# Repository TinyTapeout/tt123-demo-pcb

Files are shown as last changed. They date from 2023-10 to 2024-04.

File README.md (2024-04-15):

# TinyTapeout Demo Board for chips TT01, TT02 & TT03 



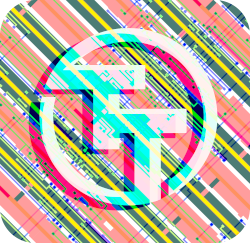
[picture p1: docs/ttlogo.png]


[TinyTapeout](https://tinytapeout.com/) is an educational project that makes it easier and cheaper than ever to get your digital designs manufactured on a real chip!

# PCB

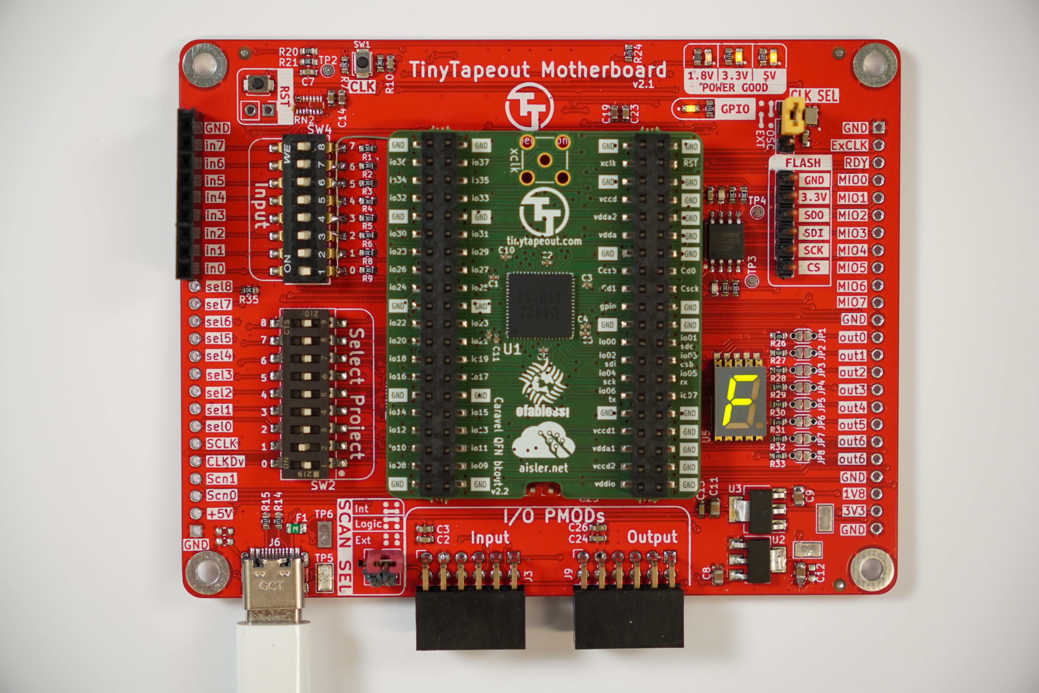
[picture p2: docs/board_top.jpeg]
boards


[More photos](https://photos.google.com/share/AF1QipMfPNW5h1ToMmdxPiXkDxMh_URZRe7d-SqbOogF8Wc6BN0UmT55_Mc50GN2rfgwhA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)

# Pinout and Quickstart

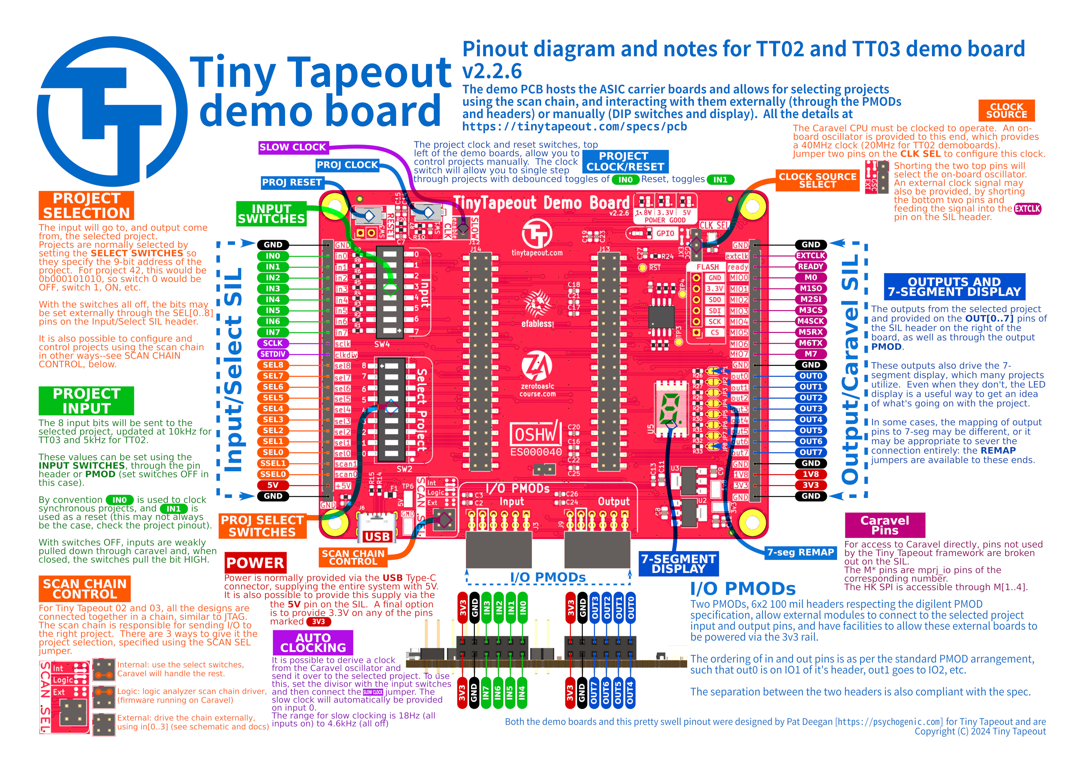
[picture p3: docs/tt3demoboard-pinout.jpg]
pinout


# Setup

Select the design you want to load. See here for all the designs:

* https://tinytapeout.com/runs/tt01/
* https://tinytapeout.com/runs/tt02/
* https://tinytapeout.com/runs/tt03/

Plug in the power via USBC and the design should be active. See the documentation for the design for how to test.
If there are no docs, open an issue on the design's repo!

## Clock divider

To slow down the generated clock:

https://github.com/TinyTapeout/tinytapeout-02/blob/tt02/INFO.md#clock-divider

## Firmware

You shouldn't need to update the firmware in most cases.

If you need firmware for external scan controller you can get the firmware from here:

https://github.com/TinyTapeout/tinytapeout-02/tree/tt02/verilog/dv/scan_controller_ext

Compile and flash using the Makefile.

## We are very happy to be sponsored by

* [Efabless](https://efabless.com/)

## Features

* Lots of testpoints, big ground pads
* Expose useful signals from ASIC:
  * ready - the sync pulse when the chain is updated
  * slow clock
  * the safety scan chain pins (all those starting with ext_scan...)
  * Expose flash programming on a standard cheap footprint for some common USB FTDI programmer
* Lots of explanatory silkscreen
* Board version and link to this repo on the silkscreen
* USB C PSU, 3.3v and 1.8v
* Adjustable clock / single step
* 9 DIP switch for design select (or jumpers)
* 8 DIP switch for inputs - should last for some fiddling but don’t need to be too heavy duty - could be buttons.
* 8 LEDs for outputs: 7 segment display inc dot
* Include PMOD headers for IOs
* Pluggable into breadboard
* Flash for firmware used to setup GPIO
* Work for TT01, TT02 & TT03
* Design for test - single sided probe test points, mounting / alignment holes

## Flashing

[See the firmware repo here](https://github.com/TinyTapeout/tt123-demo-fw)

## CHANGELOG

See [CHANGELOG.md](CHANGELOG.md)

## Resources

* [Technical info on the chip, pinout, scanchain](https://github.com/TinyTapeout/tinytapeout-02/blob/tt02/INFO.md)
* [Breakout PCB](https://github.com/TinyTapeout/breakout-pcb)
* [Datasheet on Caravel: the padring and management core](https://caravel-harness.readthedocs.io/en/latest)
* Logo created at [oshwmark by CapableRobot](http://oshwmark.capablerobot.com/)

## License

* The PCB is licensed under the [Apache2 License](LICENSE)
* The documentation is licensed under the [CC0 License](CC0_license)

## Open Source Hardware

[ES000040](https://certification.oshwa.org/es000040.html)

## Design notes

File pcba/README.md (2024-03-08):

PCB assembly files
Current version 2.2.5 boards.

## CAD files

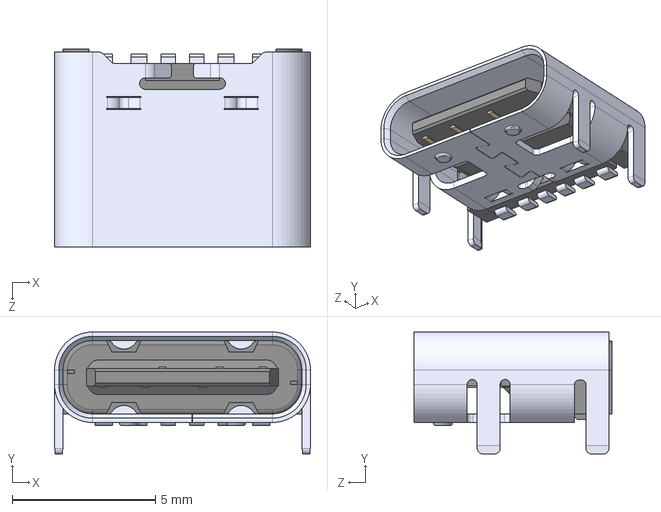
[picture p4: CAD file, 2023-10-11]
3dmodels/UJC-HP-3-SMT-TR.step
8.94 x 4.26 x 6.90 mm

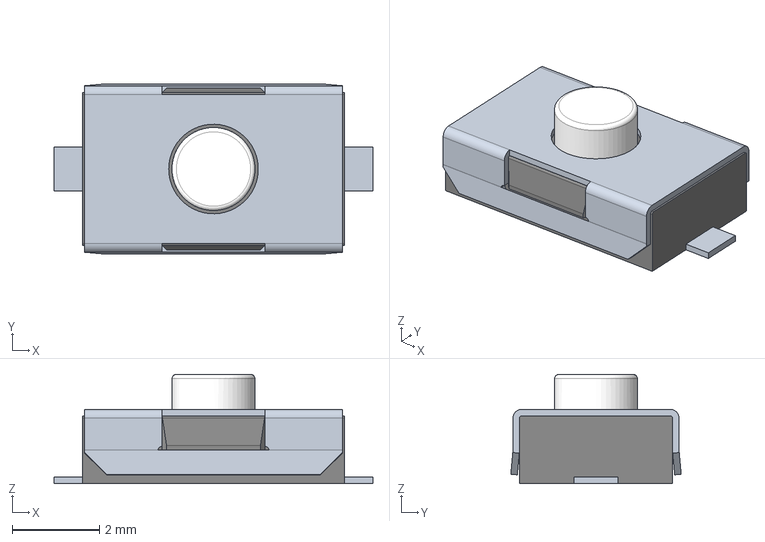
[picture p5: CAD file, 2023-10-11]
3dmodels/434121025816.step
7.30 x 3.90 x 2.50 mm

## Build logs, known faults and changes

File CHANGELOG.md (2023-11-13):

# Changelog

## [2.2.5] - 2023-11-13

7-segment display used required new footprint: created and placed. Tests indicate caravel may be clocked up to about 28MHz, osc changed to 20MHz.  Added a DNP pull-up for nRST, just in case internal isn't around or doing the job.  DNPed PMODs.

## [2.2.4] - 2023-10-27

Fix for bring-up discovery of Caravel reset issue.  The pull-up on the ~RESET pin is insufficient for stable power-up: it rises along with the supply and glitches operation.  Tests show adding a cap to delay transition looks sufficient for decent boot.

Also exposed the slow clock config/enable using jumper (J12)

## [2.2.3] - 2023-10-11

Minor tweaks for pick&place and silkscreen adjustments.

## [2.2.2] - 2023-10-06

Component replacements for PCBA/costing and related layout work.

### Major changes

- Tactile switches swapped out for bigger components
- LDOs swapped out for more efficient components
- USB-C connector changed for unit that only handles power
- layout positioning of 1 symbol -> 2 placements for carrier board

## [2.2.0] - 2023-10-01

Rework and complete re-route for the TT 1-3 mainboard.

### Major changes

- Flipped the input DIP switch so physical and logic match-up (ON is high)
- Fix: reset and clock only affect project, i.e. mapped to in 0 and 1
- Fix: debouce circuits reworked, positive edge on button press
- Mapped Caravel HK SPI to Pico
- Remapped external pin headers
- Removed resistor networks as we can rely on caravel pull-downs
- Routed such that manual remap of output to 7-segment display won't involve avoiding traces while cutting jumpers   

## [2.1.0] - 2023-07-19

Mainboard for TT 01, 02 and 03 released, with DIP switches for inputs and selection, PMOD I/O,
7-segment display and Raspberry Pi Pico footprint.

This is the preliminary release of the schematic, for review and prototyping.

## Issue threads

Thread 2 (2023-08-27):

Make it easier to remove the carrier board

mattvenn, 2023-08-27:
Removing the carrier is very hard. Maybe add pokey hole to push it out from the back?

psychogenic, 2023-08-28:
Hm, could you describe your vision/requirements for this pokey hole?  This is a 2-layer board and the Pico is right under there... so what's a pokey hole that's better than just levering the thing out, but is doable without too much disruption?

mattvenn, 2023-08-29:
updated title and comment.
the issue atm is that you can't flash it with the board in place, so every time I tried new firmware I had to lever it out
I bent the pins after a few levering outs

psychogenic, 2023-10-11:
There's no good way to do this... I think it matters little, now that we can program the flash in place through HK SPI.  Suggest we close.

Closed 2023-10-11.

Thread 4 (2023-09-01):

fix the dip switches so that on is on

mattvenn, 2023-09-01:

psychogenic, 2023-10-11:
Handled in v2.2.x, removed resistor networks as we can count on chip PDs, using pull-up only on inputs, flipped things around for input dip switch.

Closed 2023-10-11.

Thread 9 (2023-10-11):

name change - from mother board to demo board.

mattvenn, 2023-10-11:
change silk text on the front to 'TinyTapeout demo board'
update schematic from 'motherboard' to 'demo board'

psychogenic, 2023-10-11:
Changed for v2.2.3, fab run #2

Closed 2023-10-11.

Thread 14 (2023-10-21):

do we need an 'enable clock divider' toggle

mattvenn, 2023-10-21:
at the moment, you have to put a jumper between clkdv and 3.3v to enable it

mattvenn, 2023-10-22:
and would be good to visibly see it easily

mattvenn, 2023-10-23:
can see it with a firmware change to show it on the management gpio

psychogenic, 2023-10-24:
You're thinking just a 2-pin jumper to high for this?  And visibility: can we pwm the gpio pin at the rate of that clock, or something like that?

mattvenn, 2023-10-24:
yes exactly, just a 2 pin jumper. ATM I have to have a wire handy to connect the clkdiv pin to 3.3v. Something like what we have for the scan chain drive select.

I've already got a firmware that shows the frequency on the gpio led. So that's already working.

psychogenic, 2023-10-27:
Have this as a jumper, next to manual clock MOM.
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

Closed 2023-11-09.

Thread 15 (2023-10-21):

change oscillator to 20M?

mattvenn, 2023-10-21:
needs testing first

psychogenic, 2023-10-24:
We can test by feeding in 20M and changing the clock select jump.  But did we need something with a funny duty cycle for this to work?  If so, would that be true for TT3 as well?

mattvenn, 2023-10-24:
Yes, we did test this a bit in the bringup. TT3 has a different chain that should mean we can just use an oscillator.
I'll check how fast we can go with a 50% duty cycle and then make a call on the oscillator for TT2

mattvenn, 2023-11-09:
tested up to 28M, so let's go with a 20M oscillator

https://discord.com/channels/1009193568256135208/1162346245088608366/1166759290665705485

psychogenic, 2023-11-13:
Ok, done, changed for a 20M WE osc with same footprint.

psychogenic, 2023-11-13:
Changed to 830208220401, another Wurth IQXO-791 series osc.  It's the hi-fi version with the same footprint (only the best for my TT friends) but the 831056293 could probably do the trick as well, for a few pennies less.

Closed 2023-11-13.

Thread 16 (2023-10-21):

Something wrong with power up initialisation

mattvenn, 2023-10-21:
the board takes some amount of time before it starts working.

## tests

Power on and wait for chain to start

board d part 2

-  2:15
-  1:30
-  2:40
-  1:48
-  1:03

Board c part 1

-  2:30
-  0:40
-  1:15

## reset test

Hold in reset for 3 mins
Release and wait for chain to start

- 0:00
- 0:00
- 0:00
- 0:00

Selected design's led segments are immediately visible when powered up while reset asserted

## other observations

Another clue: once it's working it stays working. Can change to ext or la mode and scan chain always comes back
I can also power off, ground both select pins, wait 5 seconds, power on and it still continues to work

to go back to 'non working state' needs a few minutes.

## thoughts

unitialised state? but there isn't any reg larger than 9 bits in the scan controller https://github.com/TinyTapeout/tinytapeout-02/blob/tt02/verilog/rtl/scan_controller/scan_controller.v

Is reset ok? even with chip held in reset with a wire doesn't help

Pull-ups/ downs by caravel won't work until after reset.
So either need to be added to the board or might be resolved by some firmware?

even with the select pins both pulled high directly with wires when board starts, still there is this variable delay

mattvenn, 2023-10-22:
Takes 260 led flashes for board 2 to start

mattvenn, 2023-10-23:
missing pulldowns on design select and wrong setting in the firmware led to the scan chain state machine getting confused
fixed with firmware

Closed 2023-10-23.

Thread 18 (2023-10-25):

feedback on v2.2.3

mattvenn, 2023-10-25:
* DNP memory programming header
* DNP PMOD header
* 7 seg not soldered properly on 2 of 4 boards
* board doesn't reset properly
* reset is floating
* reset should be renamed to n_reset

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

floating reset (is pulled up by internal caravel)
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

works with a 1uf cap soldered between reset and gnd:
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

psychogenic, 2023-10-27:
Have set the DNPs at Aisler.  Have the reset RC cap solution in latest rev, as well as the ~rst naming on the symbol.

psychogenic, 2023-11-13:
Headers J1, J3 and J9 are DNPed and excluded @ aisler.  WE 7-seg footprint was different enough to warrant a new one, which I created and populated. nRST cap fix applied, and added a DNP pull-up in case we find the internal isn't around or doing the job.  Submitted as revision 11 @ aisler, closing issue.

Closed 2023-11-13.

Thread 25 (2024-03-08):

feedback on the pinout doc

mattvenn, 2024-03-08:
contrast of the 7-seg could be improved.

7 seg looks a bit weird
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

Follow branding guidance (TinyTapeout -> Tiny Tapeout) (saw a ref to tinytapeout in scanchain control)

Would re-write this:
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

to:

The clock and reset buttons are debounced switches connected to inputs 0 and 1 respectively. Not all projects use this convention, but for those that do, these are convenient ways to manually single step and reset.

would rewrite the 40M clock part of this:
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

to:

which provides a 40MHz clock (20MHz for TT02 demoboards)

Rewrite this:
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

To use this, set the divisor with the input switches and then connect the slow clk jumper. The slow clock will automatically be provided on input 0.

Hard to fit in, but a few examples of slow clock settings would be nice, like the min and max :
all off = 2.3kHz
all on = 9Hz

Rewrite 'as fast as scanchain can manage' here:
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

To: 10kHz for TT03 and 5kHz for TT02.

run a spellcheck on the text. I saw a few: seperation -> separation. there might be more.

mattvenn, 2024-03-08:
Also please add the pinout diagram into this repo

psychogenic, 2024-03-08:
All changes made, hacked up 7-seg image, pinout uploaded and in readme.

psychogenic, 2024-03-08:
Done

Closed 2024-03-08.

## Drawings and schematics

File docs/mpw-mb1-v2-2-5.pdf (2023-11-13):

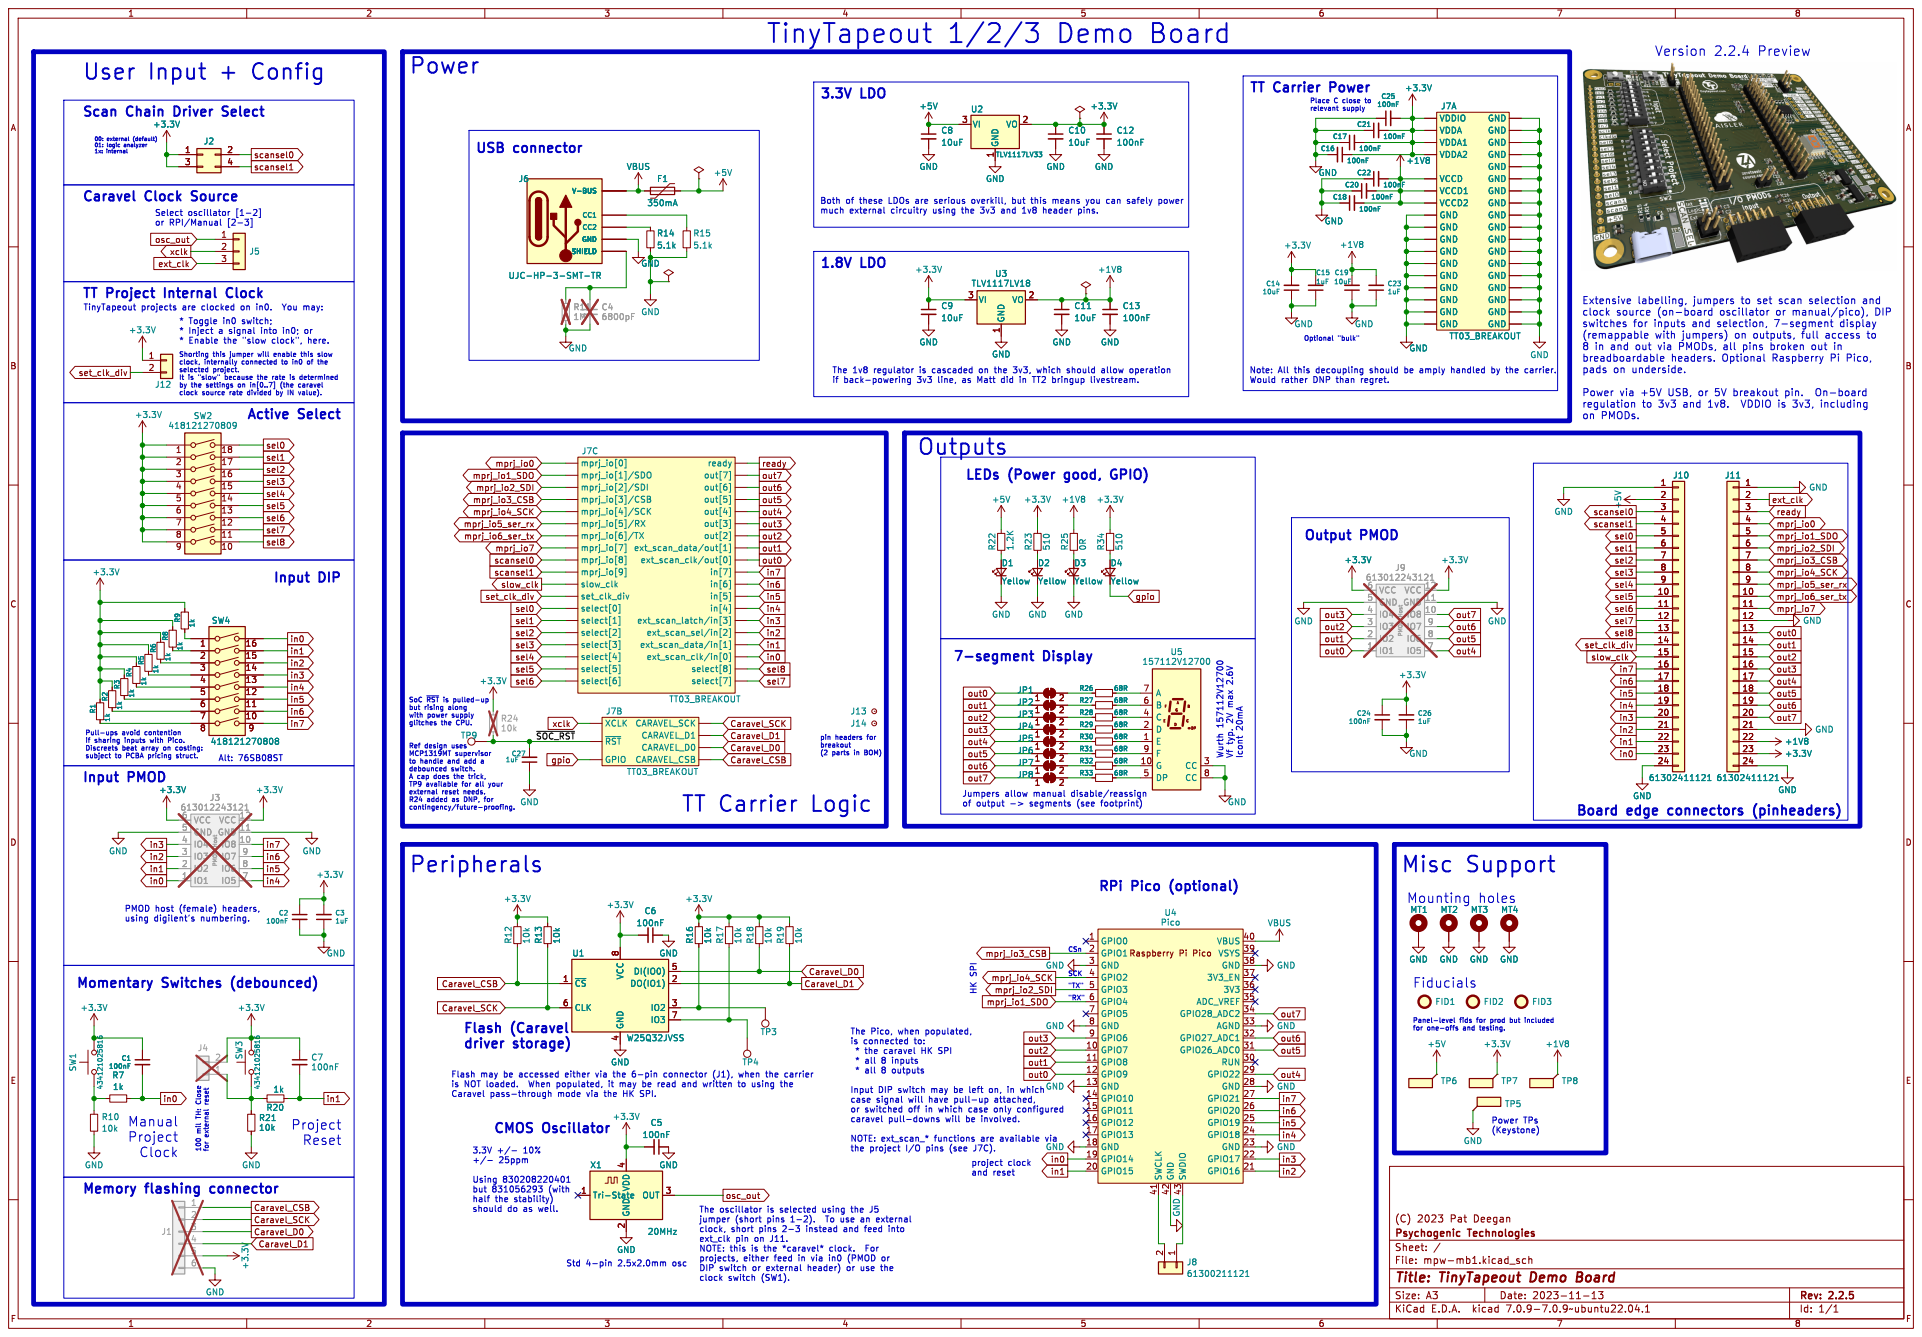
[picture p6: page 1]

Scan Chain Driver Select

1 VO 2 VI 3 U3 TLV1117LV18 +3.3V GND GND

J6 UJC-HP-3-SMT-TR

GND GND GND GND GND

8 in and out via PMODs, all pins broken out in

LEDs (Power good, GPIO)

SoC ~{RST}is pulled-up

to handle and add a

project clock and reset TT Carrier Logic

half the stability) should do as well. Flash (Caravel
driver storage)

The Pico, when populated,

Input DIP switch may be left on, in which

Id: 1/1 Title: TinyTapeout Demo Board

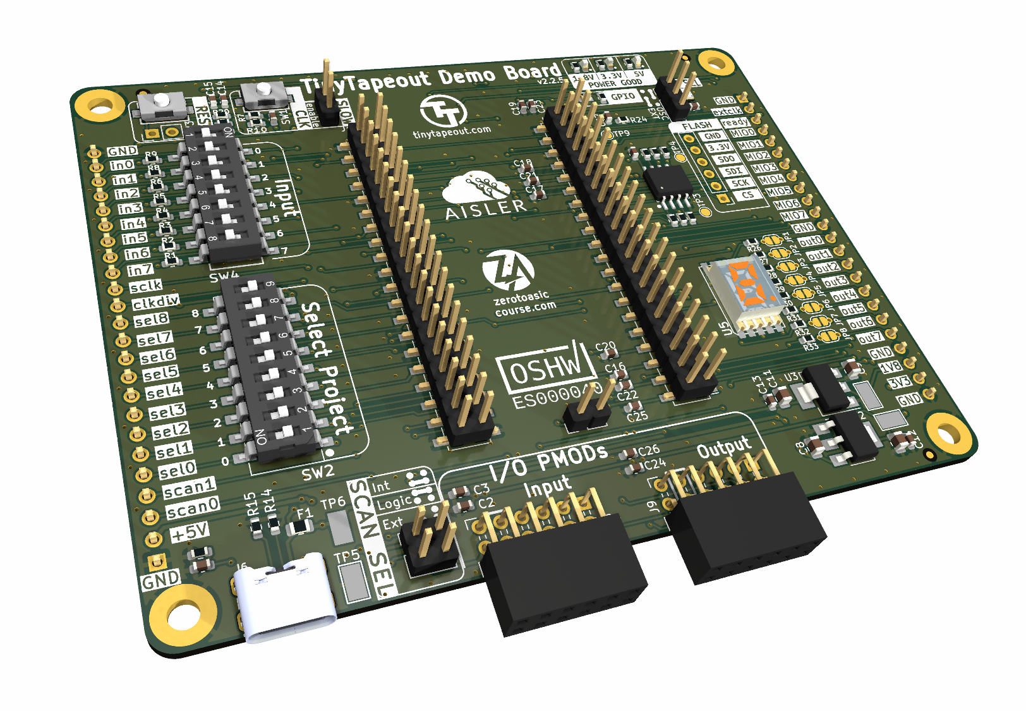
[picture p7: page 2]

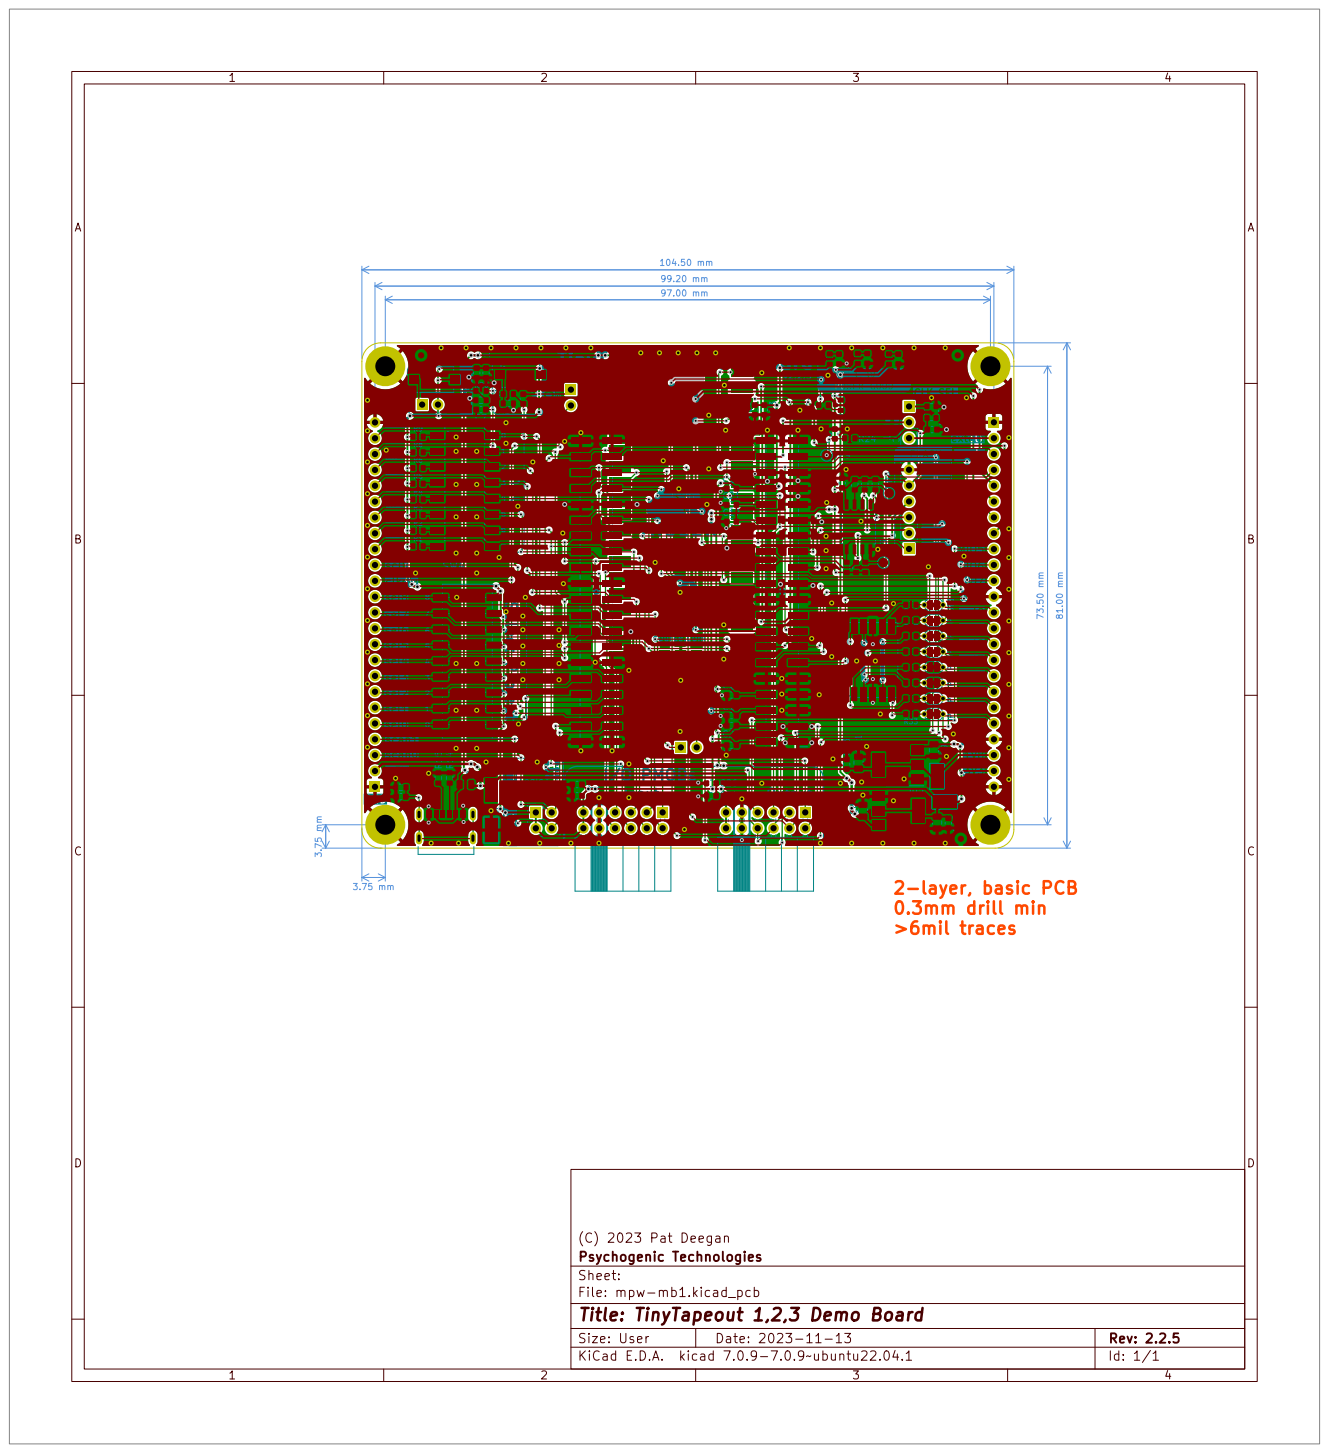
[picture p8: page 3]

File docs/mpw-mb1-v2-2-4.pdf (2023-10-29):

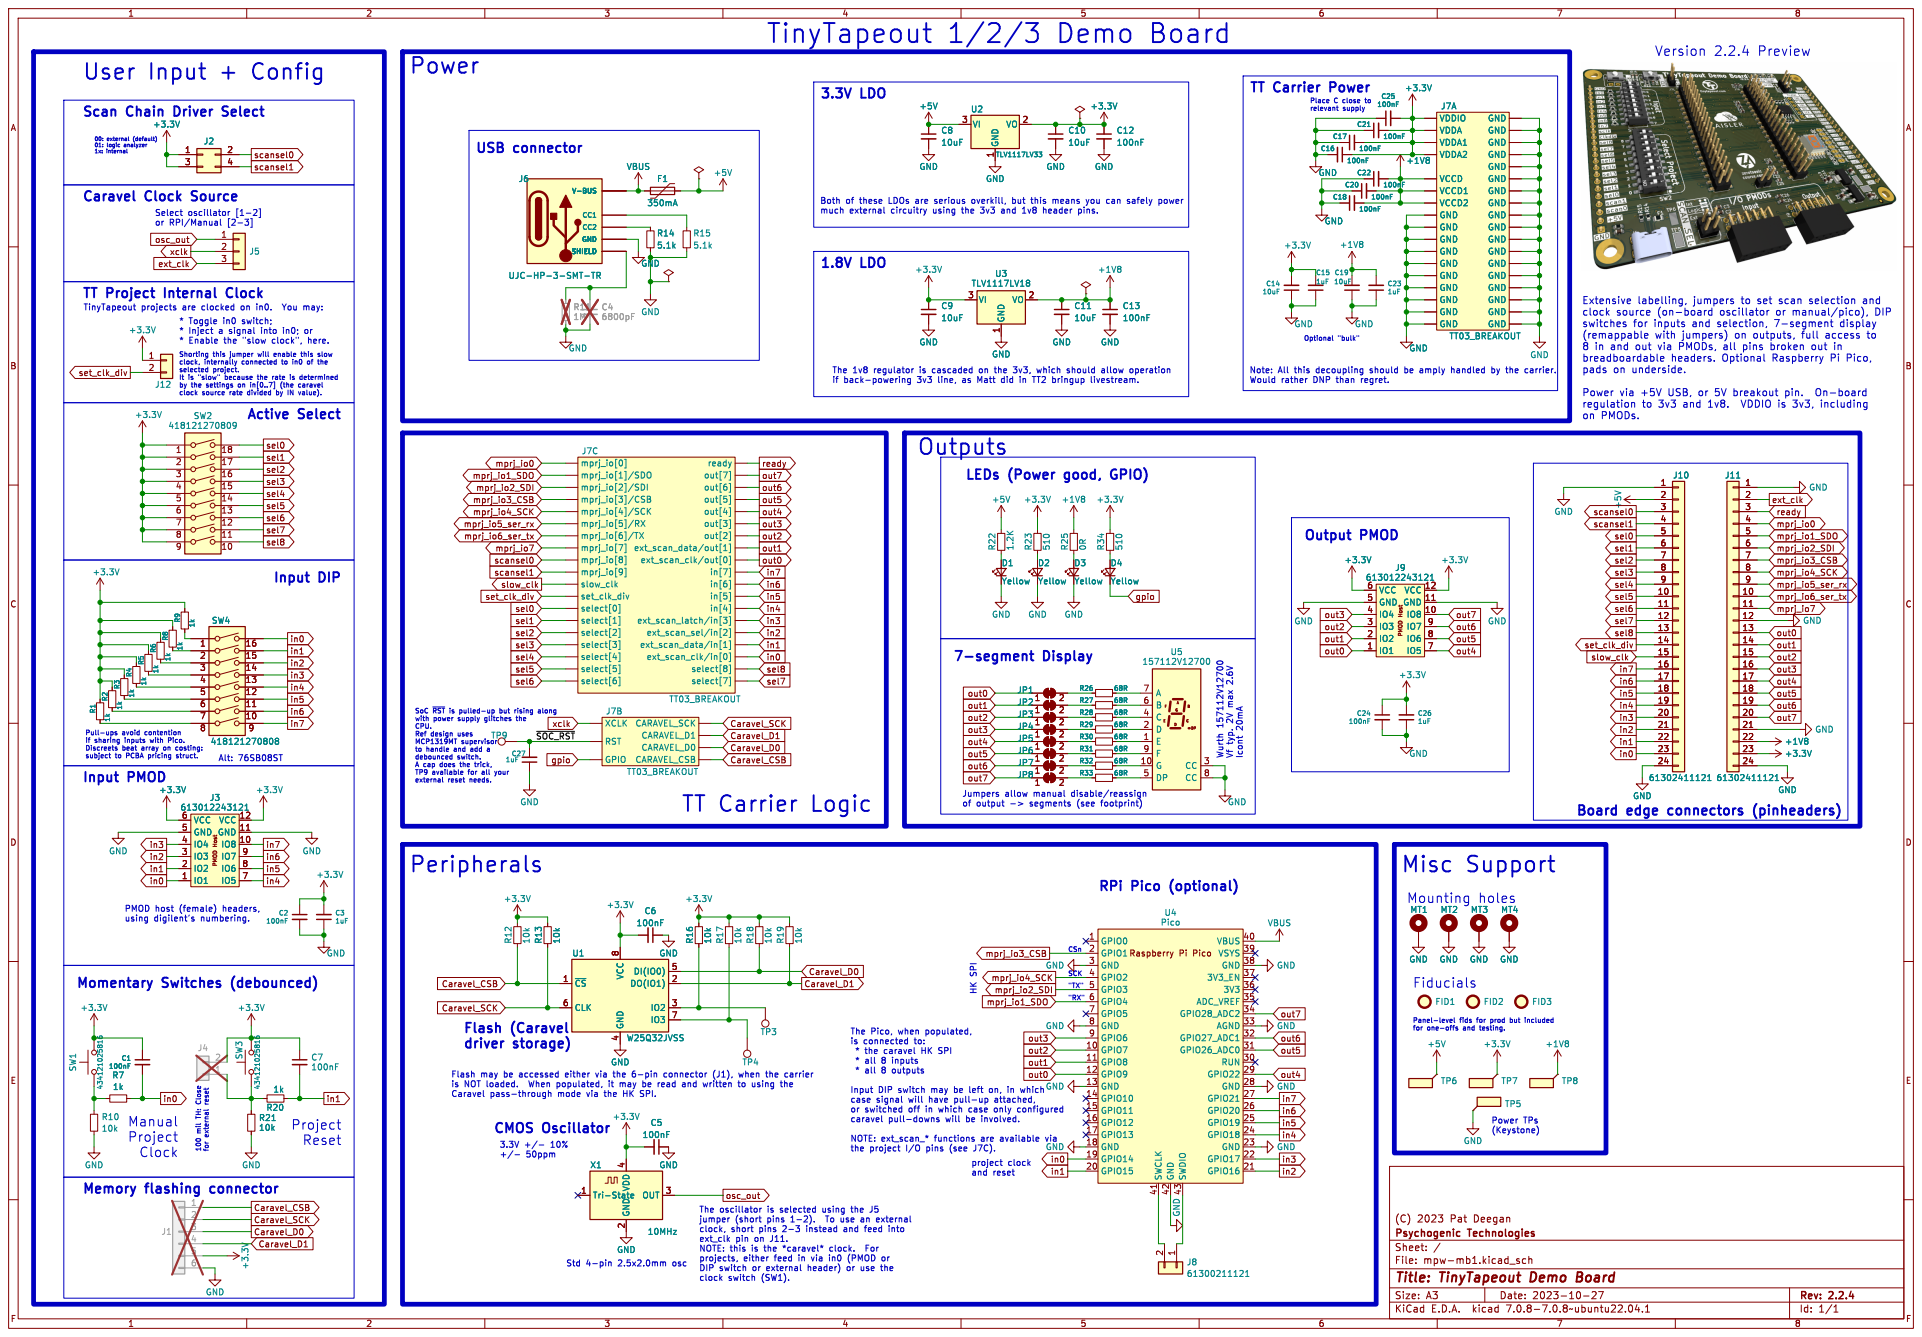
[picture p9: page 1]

J6 UJC-HP-3-SMT-TRGND
CC1 V-BUS CC2 SHIELD

J6 UJC-HP-3-SMT-TR

TT Project Internal Clock

8 in and out via PMODs, all pins broken out in

LEDs (Power good, GPIO)

to handle and add a

Board edge connectors (pinheaders)

Input DIP switch may be left on, in which

the project I/O pins (see J7C).

Id: 1/1 Title: TinyTapeout Demo Board

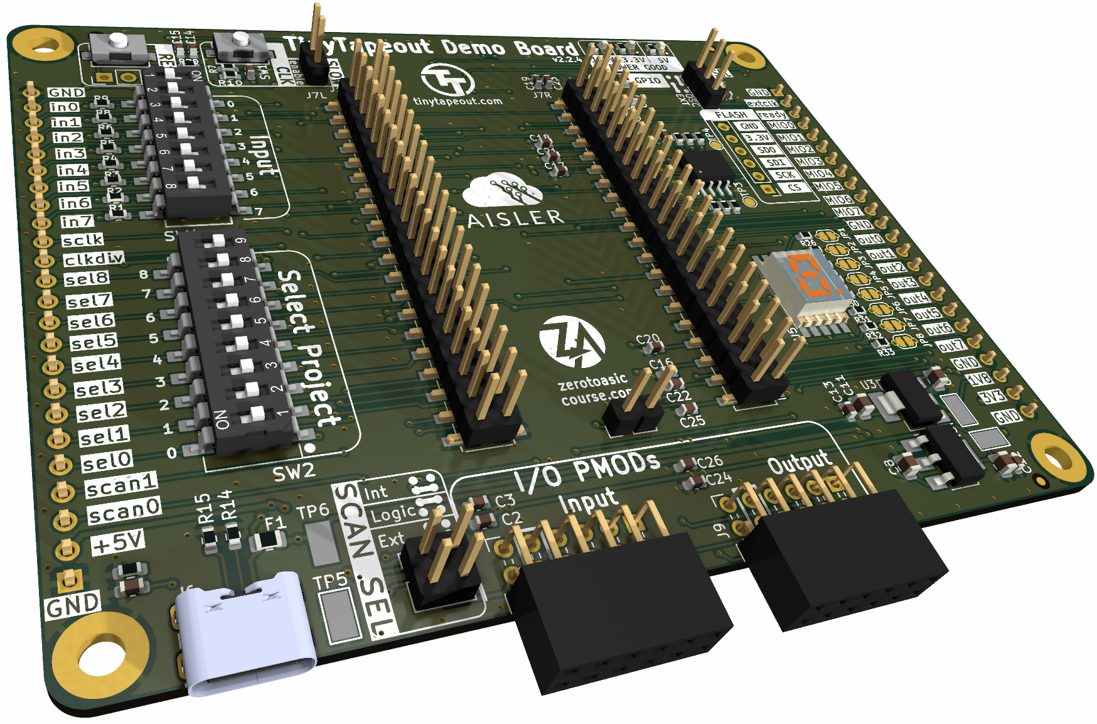
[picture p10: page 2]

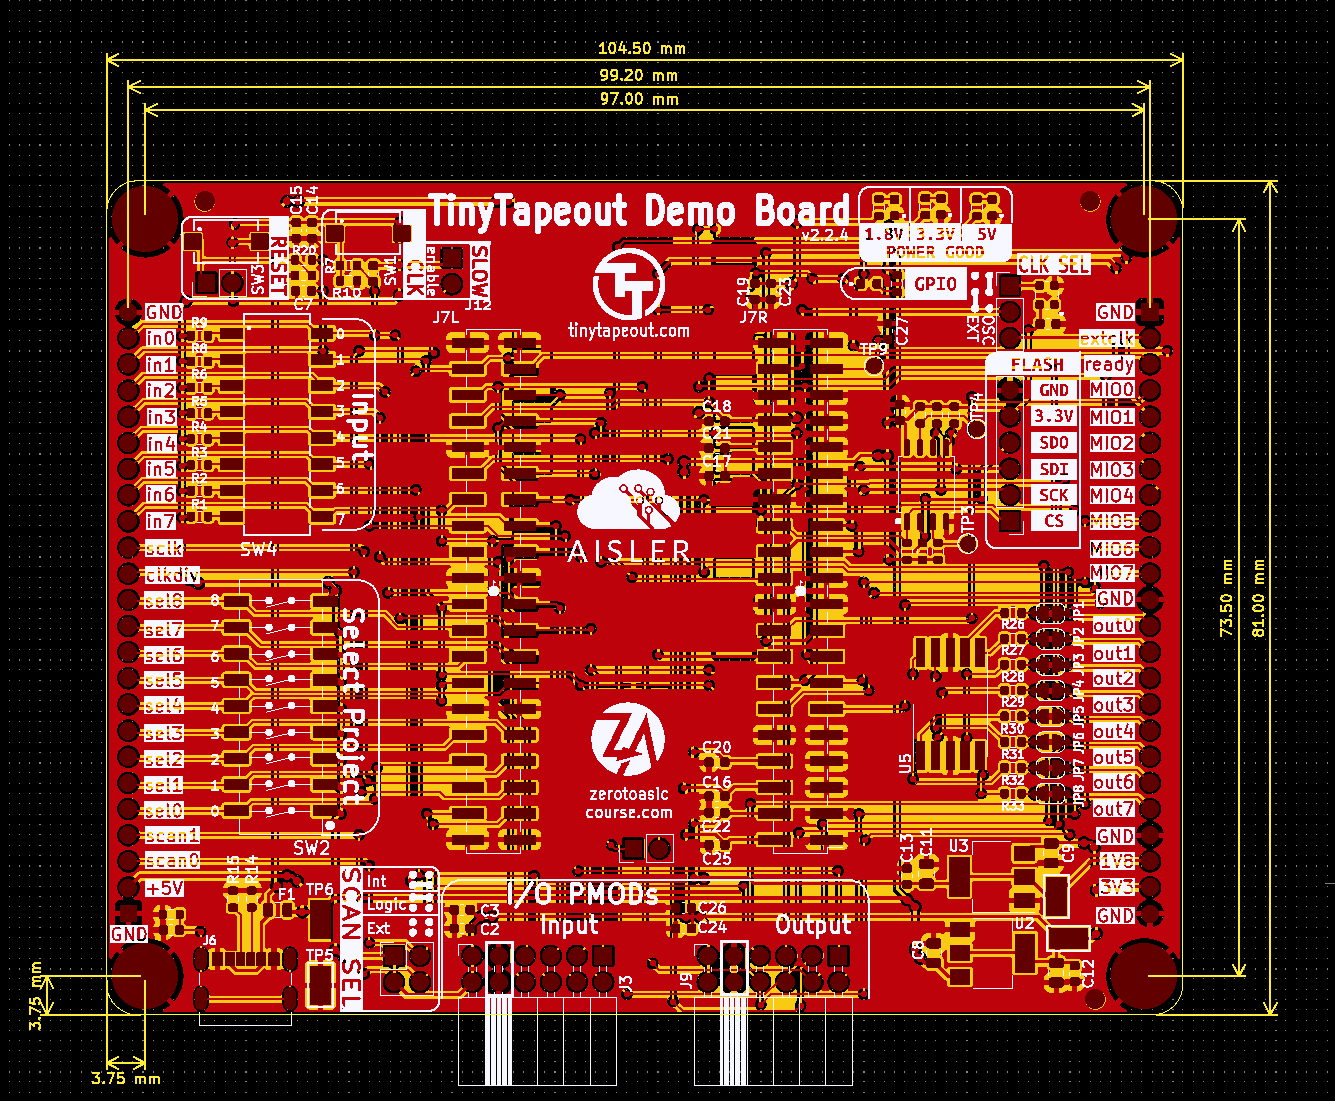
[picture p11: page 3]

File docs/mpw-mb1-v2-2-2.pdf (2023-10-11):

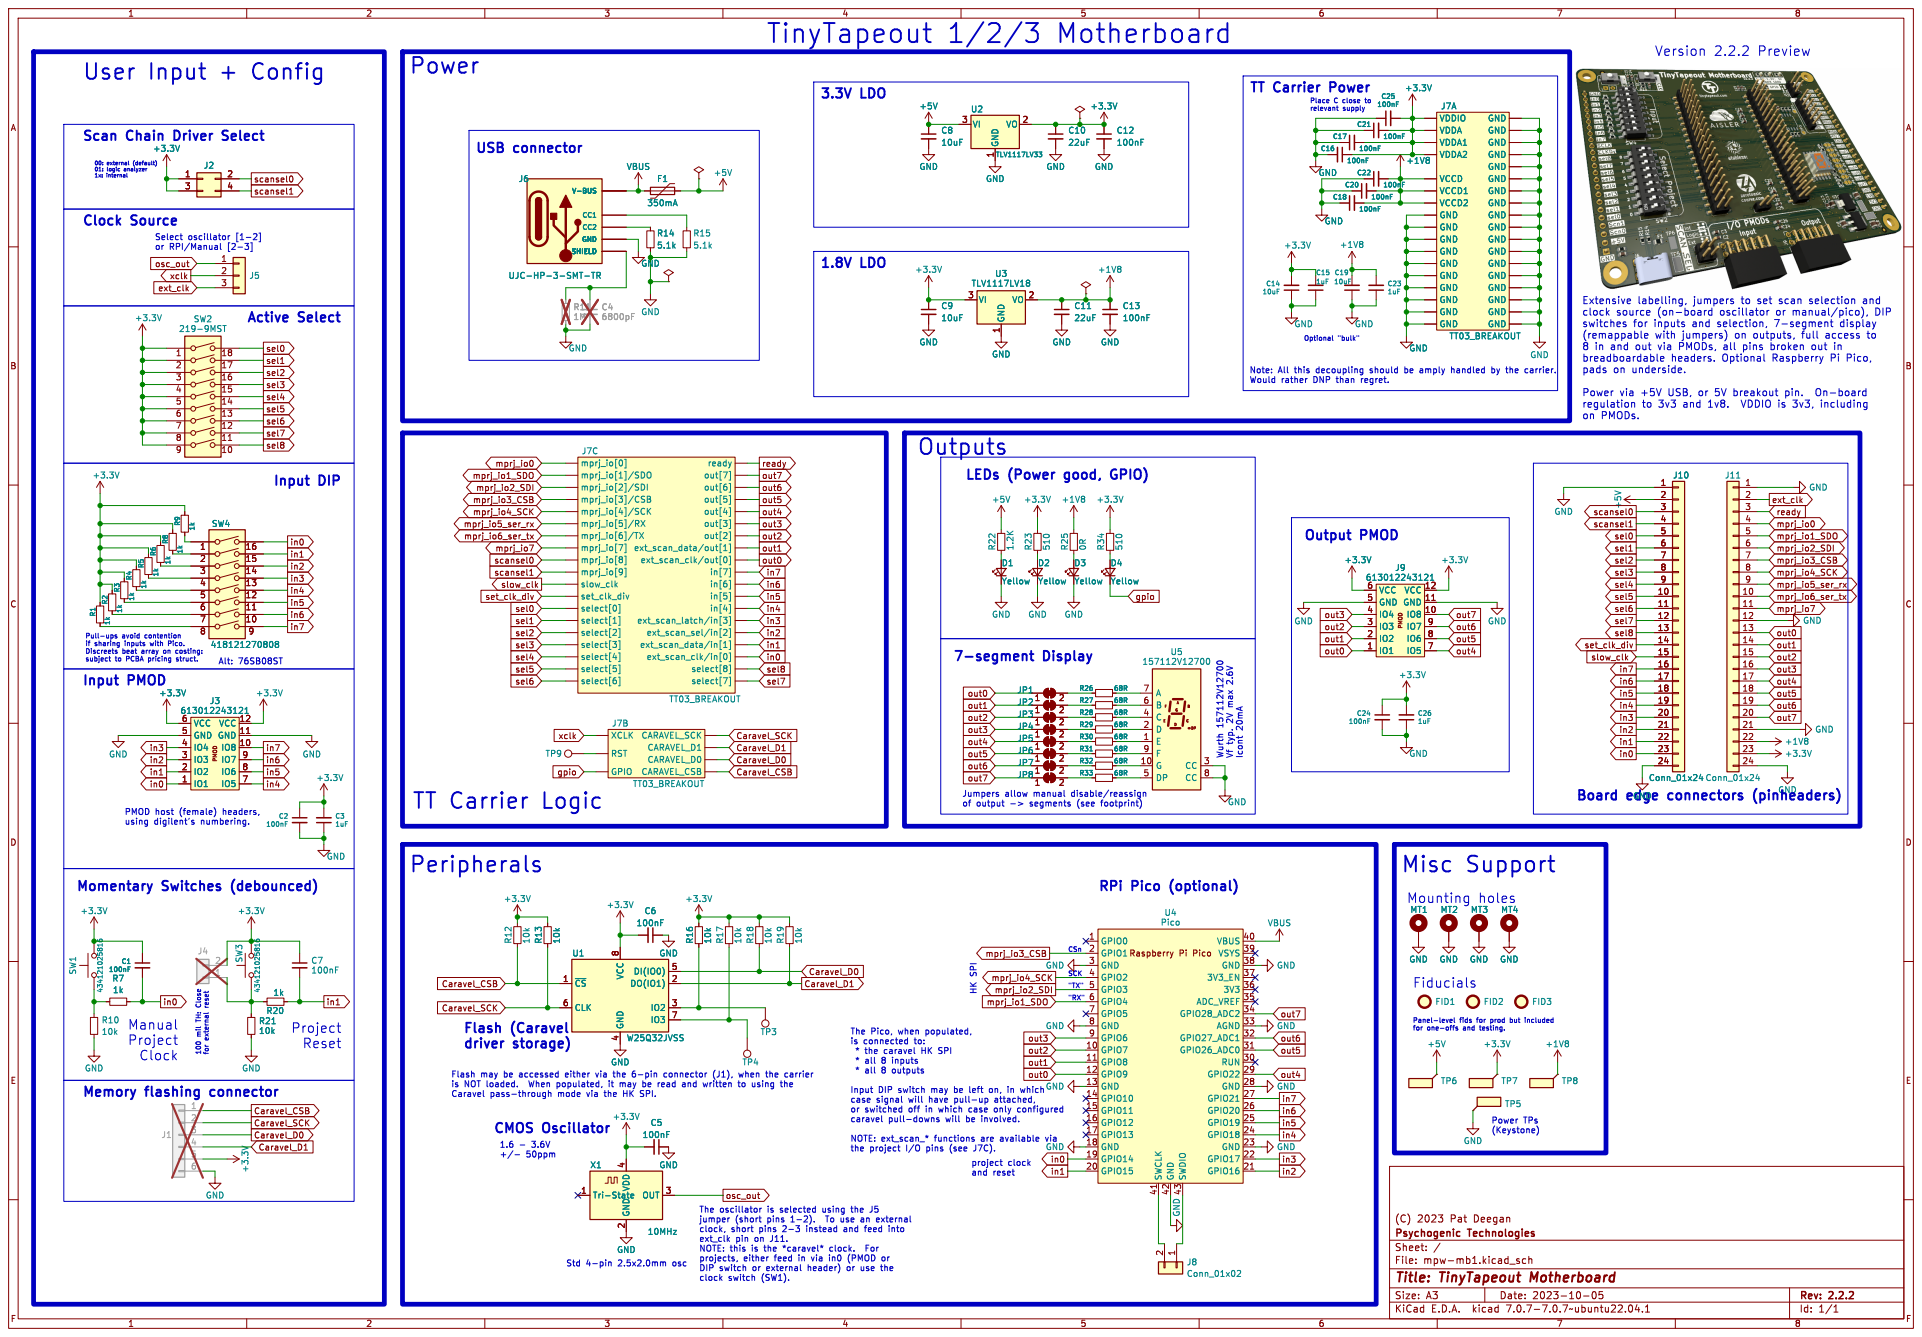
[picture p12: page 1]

SCK User Input + Config

1 VO 2 VI 3 U3 TLV1117LV18 GND GND GND GND

GND GND GND GND GND

J6 UJC-HP-3-SMT-TR

8 in and out via PMODs, all pins broken out in

out7
Jumpers allow manual disable/reassign

CSn Momentary Switches (debounced)

Input DIP switch may be left on, in which

project clock and reset

Id: 1/1 Title: TinyTapeout Motherboard

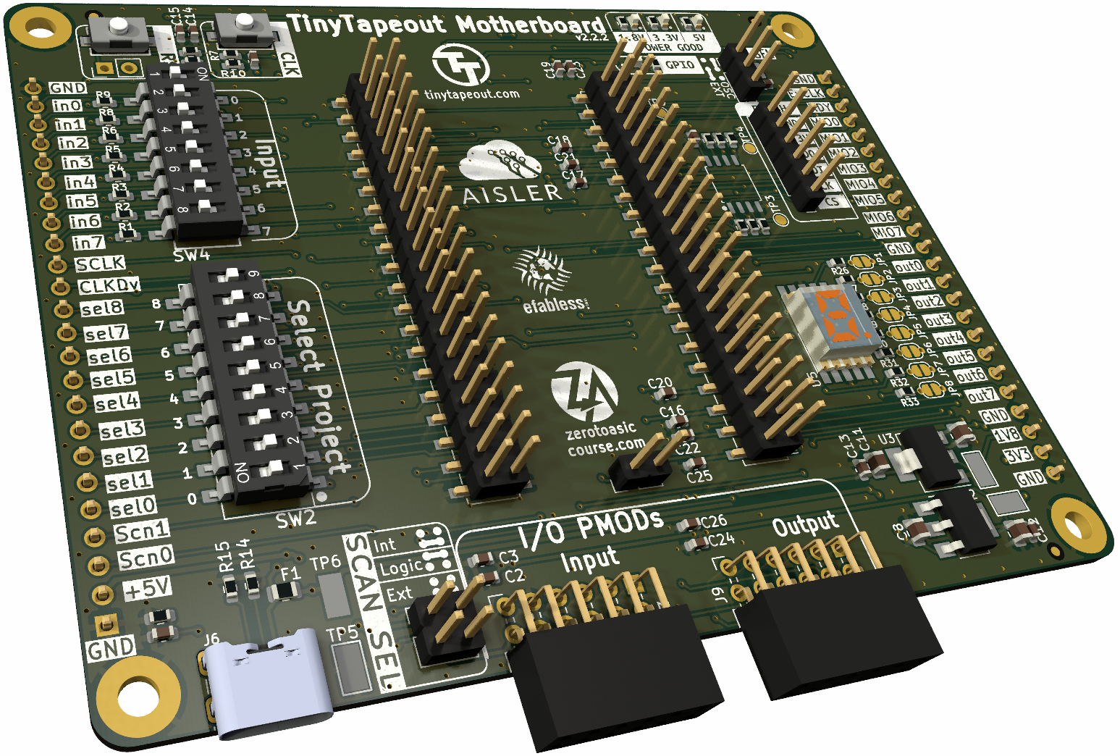
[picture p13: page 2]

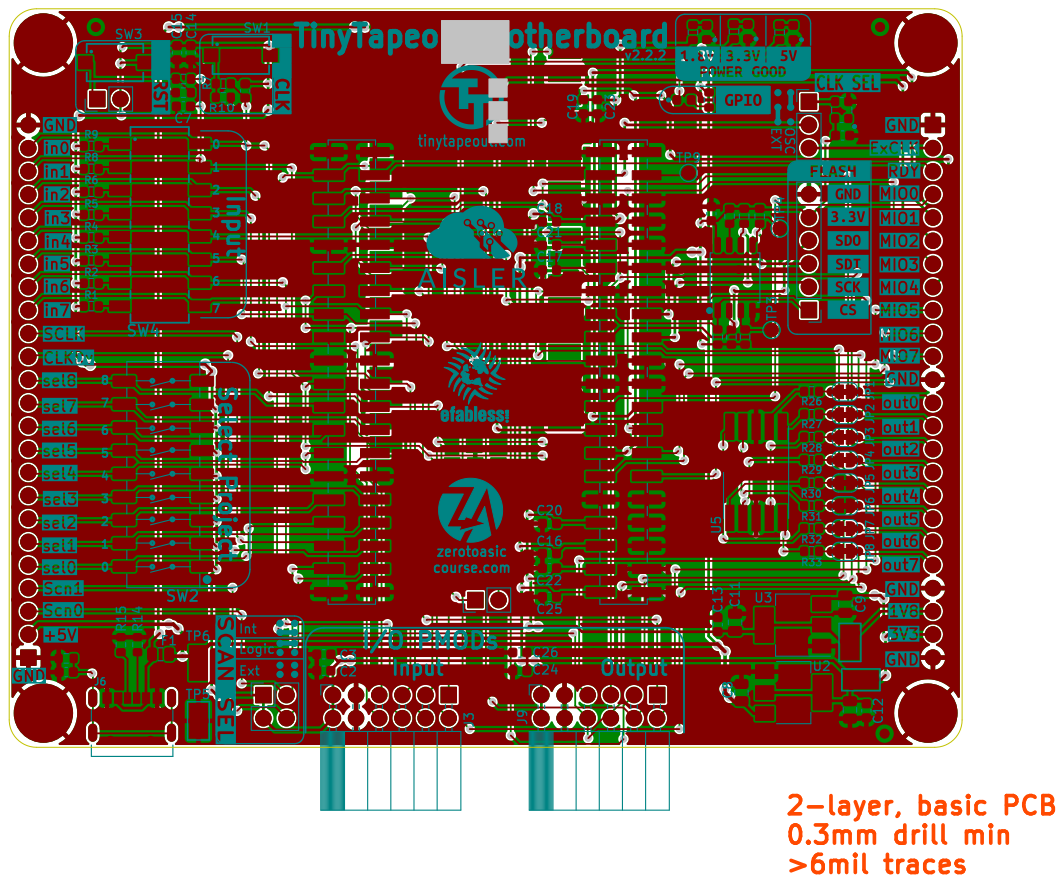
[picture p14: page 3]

Id: 1/1 Title: TinyTapeout 1,2,3 Motherboard

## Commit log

2023-03-17 Initial release
    Initial release
    [mpw-mb1.kicad_pcb, mpw-mb1.kicad_sch]
2023-06-21 kicad 7 migration
    [mpw-mb1.kicad_pcb, mpw-mb1.kicad_sch]
2023-06-28 TT0[1-3] motherboard basic schem
    [mpw-mb1.kicad_sch]
2023-06-28 Libs move, starting on pico
    [mpw-mb1.kicad_sch]
2023-07-05 custom pmod symbol and footer to match digilent pinout
    [mpw-mb1.kicad_sch]
2023-07-05 basic placement started
    [mpw-mb1.kicad_pcb, mpw-mb1.kicad_sch]
2023-07-05 prelim floorplan done
    [mpw-mb1.kicad_pcb, mpw-mb1.kicad_sch]
2023-07-18 v2.0 alpha, routing complete
    [mpw-mb1.kicad_pcb, mpw-mb1.kicad_sch]
2023-07-19 v2.1 release
    [mpw-mb1.kicad_pcb, mpw-mb1.kicad_sch]
2023-07-27 cleanup, additions for BOM (MPNs...)
    [mpw-mb1.kicad_sch]
2023-08-23 v2.1 prototype run
    [mpw-mb1.kicad_pcb, mpw-mb1.kicad_sch]
2023-09-30 Fixes and rewire: manual clock and reset, input pull-ups value lowered
    [mpw-mb1.kicad_pcb, mpw-mb1.kicad_sch]
2023-10-01 rewire, pre track delete
    [mpw-mb1.kicad_pcb, mpw-mb1.kicad_sch]
2023-10-01 track/via global deletion, floorplan, basic power delivery
    [mpw-mb1.kicad_pcb, mpw-mb1.kicad_sch]
2023-10-01 routing v2.2 complete
    [mpw-mb1.kicad_pcb]
2023-10-01 schem new render
    [mpw-mb1.kicad_sch]
2023-10-01 schematic cleanup and user notes
    [mpw-mb1.kicad_sch]
2023-10-01 version number update and PDF doc
    [mpw-mb1.kicad_pcb]
2023-10-01 track cleanup, better fills
    [mpw-mb1.kicad_pcb]
2023-10-03 Move HK SPI to first CSn pin on Pico
    [mpw-mb1.kicad_pcb, mpw-mb1.kicad_sch]
2023-10-05 v2.2.2: part swaps as per Aisler requests, re-route relevant sections
    [434121025816.step, UJC-HP-3-SMT-TR.step, mpw-mb1.kicad_pcb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]
2023-10-06 carrier 1 symbol -> 2 placements fix
    [mpw-mb1.kicad_pcb]
2023-10-06 3d model tweaks
    [mpw-mb1.kicad_pcb]
2023-10-11 v2.2.3 mods for pnp, silkscreen tweaks.
    [mpw-mb1.kicad_pcb, mpw-mb1.kicad_sch]
2023-10-11 Create .gitignore
    Added .gitignore file to keep the repository clean from temporary files created by KiCad.
2023-10-11 Updated crystal oscillator to 831061624 by Wurth
    Updated the crystal oscillator to the 831061624 by Wurth, the base specifications are compatible apart from the supply voltage which only supports 3V3, the documentation in the schematic has been updated accordingly.
    [mpw-mb1.kicad_sch]
2023-10-11 Include 7 Segment MPN in Symbol for automated matching
    [mpw-mb1.kicad_sch]
2023-10-11 Add MPN to 2X2 header
    Adding Wurth MPN to the 2X2 header (61300421121)
    [mpw-mb1.kicad_sch]
2023-10-11 Update MPN of 1X3 header to use Wurth part
    Updated the MPN of the 1X3 header from a Amphenol to Wurth part (61300311121)
    [mpw-mb1.kicad_sch]
2023-10-11 Update MPN of 9 Pole SMD switch
    Update the MPN of the 9 Pole SMD switch to Wurth component. ( 418121270809)
    [mpw-mb1.kicad_sch]
2023-10-11 Update MPN of 1X6 connector to use Wurth component
    Updated the MPN of the 1X6 component to use a Wurth part (61300611121)
    [mpw-mb1.kicad_sch]
2023-10-11 Update 1X24 Pin header to use Wurth part
    Updated the 1X24 Pin header at the edge of the board to use a part from Wurth (61302411121)
    [mpw-mb1.kicad_sch]
2023-10-11 Changed 22uF LDO Ouput capacitors to 10uF caps
    The change to 10uF allows us to reduce part variance. The 10uF should provide ample capacitance even after taking the DC-Bias into account, the TLV1117LV datasheet specifies 1uF (derated)
    [mpw-mb1.kicad_sch]
2023-10-11 Remove Resistor MPN and add infor for Smart Match
    Specific part number for resistors limit our capability to automatically find the best price, thus I removed the specific MPN and replaced them with parameter which are automatically readable by AISLERs Smart Match.
    [mpw-mb1.kicad_pcb, mpw-mb1.kicad_sch]
2023-10-11 Add Wurth MPN to 1X2 header
    [mpw-mb1.kicad_sch]
2023-10-11 Update values to PCB
    [mpw-mb1.kicad_pcb]
2023-10-11 Adding Upload to AISLER badge to README
    The AISLER badge makes it possible to order the latest PCB revision in the repository by just clicking on it.
2023-10-14 PMOD _peripheral_ symbol and footprint
2023-10-14 Using external, centralized, resource for kicad symbols/footprints
    [mpw-mb1.kicad_sch]
2023-10-27 Glitchy reset fix and slow clock divider/enable jumper
    [mpw-mb1.kicad_pcb, mpw-mb1.kicad_sch]
2023-10-27 v2.2.4 PDF
    [mpw-mb1.kicad_pcb]
2023-10-27 Updated TT breakout symbol for ~RST
    [mpw-mb1.kicad_sch]
2023-10-27 logo, logo, everywhere but not a drop to drink
    [mpw-mb1.kicad_pcb]
2023-11-13 v2.2.5: 7-seg fp, new osc, nRST pull-up
    [mpw-mb1.kicad_pcb, mpw-mb1.kicad_sch]
2023-12-06 PCBA BOM, viewer and gerbers
    [mpw-mb1-B_Cu.gbr, mpw-mb1-B_Mask.gbr, mpw-mb1-B_Paste.gbr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]
2023-12-06 placement CSV
    [mpw-mb1-all-pos.csv]
2024-02-14 v2.2.6 logo mods, BOM adjust, minor silk tweaks
    [mpw-mb1.kicad_pcb, mpw-mb1.kicad_sch]
2024-02-14 adjustments for cleaner gnd fills
    [mpw-mb1.kicad_pcb, mpw-mb1.kicad_sch]
2024-02-21 40MHz osc for TT03, minor mods to pcb stitching
    [mpw-mb1.kicad_pcb, mpw-mb1.kicad_sch]
2024-02-21 Demoboard run 2 pcba (for TT03 using v2.2.6)
    [mpw-mb1-B_Cu.gbr, mpw-mb1-B_Mask.gbr, mpw-mb1-B_Paste.gbr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]
